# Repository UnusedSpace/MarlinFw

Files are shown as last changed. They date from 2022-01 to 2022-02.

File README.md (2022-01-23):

# Dokumentation

## Inhalt

### [Marlin Firmware - Fork Unused Space](./marlinfw/readme.md)

- Hardware
- Software
- Installation
- Konfiguration

### [PrusaSlicer](./prusaslicer/readme.md)

- Installation
- Konfiguration

### [Raspberry](./raspberry/readme.md)

- OctoPrint | Raspbian
  - Installation
  - Konfiguration

- OctoPi
  - Installation
  - Konfiguration

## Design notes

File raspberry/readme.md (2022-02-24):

# Raspberry

## **Hardware**
Folgende Einplatinenrechner wurden erfolgreich getestet
| Einplatinenrechner | Version |
| :- | :- |
| Raspberry Pi 3 | B+ |
| Raspberry Pi 4 | 4GB |

Raspberry Pi Zero, Raspberry Pi Zero W werden aufgrund der erhöhten Hardwareanforderungen nicht empfohlen!
<br><br>

## **Software**

| Datei | Version (**) | Link |
| :- | -: | :-: |
| Raspberry Pi Imager | 1.6.2 | [Webseite](https://www.raspberrypi.com/software/) |
| Raspberry Pi OS Lite (*) | Bullseye - 30.10.2021 | [Webseite](https://https://www.raspberrypi.com/software/operating-systems/) |
| OctoPi & OctoPrint (*) | 0.18.0 & 1.7.3 | [Webseite](https://github.com/OctoPrint/OctoPi-UpToDate/releases) |

(*) Aufzählung dient zur Versionskontrolle und müssen bei Nutzung des Raspberry Pi Imager nicht zurätzlich herunter geladen werden. <br>
(**) Die Versionen beziehen sich auf den Zeitpunkt der Erstellung dieser Dokumentation.
<br>Als Grundsystem für diese Dokumentation liegt Windows 10 vor.

<br>

## Software - Installation | Konfiguration

<details>
<summary><b><i> Raspberry Pi Imager </i></b></summary>

Empfohlen wird eine Class10 SD-Karte mit mindestens 8GB Flashspeicher. Diese kann nun eingelegt und im Hauptmenü unter *SD-KARTE WÄHLEN" ausgewählt werden.

Vorbereitend für die beschriebenen Varianten werden folgende Konfigurationen über *Erweiterte Optionen* (erreichbar über Strg+Shift+X) getroffen:

- *Hostname* aktivieren und vergeben
- *SSH aktivieren* und Passwort vergeben
- *Wifi einrichten* aktivieren und Anmeldeinformationen eingeben
- *Spracheinstellungen festlegen* aktivieren und konfigurieren

</details>

<details>
    <summary><b><i> Variante: Raspbian & OctoPrint </i></b></summary>

Text

*   <details>
    <summary><b><i> Raspbian </i></b></summary>

    Die folgende Anleitung ist nicht als Komplettdokumentation zu sehen! Sie beschreibt lediglich einen oberflächlichen Weg zu einem funktionsfähigem Steuersystem eines 3D-Druckers.

    *   <details>
        <summary><b><i> Installation | Flash </i></b></summary>

        Über den Menüpunkt *OS WÄHLEN* wird das Image unter *Raspberry Pi OS (other) > raspberry Pi OS Lite (32-bit)* ausgewählt und über den Menüpunkt *SCHREIBEN* auf die SD-Karte übertragen.

        Nach dem Schreibvorgang kann die SD-Karte in einen Raspberry eingelegt und jener gestartet werden.

        Der Erste Bootvorgang und die Einwahl in das LAN/WLAN kann bis zu 2 Minuten in Anspruch nehmen!

        </details>

    *   <details>
        <summary><b><i> Konfiguration </i></b></summary>

        Per Kommandozeile wird nun eine SSH-Verbindung aufgebaut:

        > ssh pi@\<HOSTNAME>

        > ssh pi@\<IP>

        Im Anschluss werden folgende Einstellungen getroffen:

        Ein gesondertes Passwort für *root* setzen

        > sudo passwd

        *Raspberry Pi Software Configuration Tool* aufrufen und diverse Einstellungen treffen

        > sudo raspi-config

        - Beim Booten auf eine Netzwerkverbindung warten
            > 1 System Options > S6 Network at Boot > Yes

        - Raspberry Pi Camera-Option aktivieren
            > 3 Interface Options > P1 Camera > Yes

        - Systemsprache ändern
            > 5 Localisation Options > L1 Locale > de_DE.UTF-8 UTF-8 aktivieren
            
            > Systemsprache auf de_DE.UTF-8 ändern

        Paketlisten aktualisieren

        > sudo apt-get update

        System aktualisieren

        > sudo apt-get upgrade

        Nicht mehr benötigte bzw. nicht mehr unterstützte Pakete deinstallieren

        > sudo apt-get autoremove

        Das System neustarten, um die Änderungen zu initialisieren

        > sudo reboot now

        </details>

    </details>

*   <details>
    <summary><b><i> OctoPrint </i></b></summary>

    Text

    *   <details>
        <summary><b><i> Installation </i></b></summary>

        Text

        Abhängigkeiten nachinstallieren

        > sudo apt install python3-pip python3-dev python3-setuptools python3-venv git haproxy

        OctoPrint Ordner erstellen und aufrufen

        > mkdir OctoPrint && cd OctoPrint

        Eine virtuelle Umwelt für Octoprint aktivieren

        > python3 -m venv venv
        > source venv/bin/activate

        PIP upgraden

        > pip install pip --upgrade
        
        OctoPrint installieren

        > pip install octoprint

        User \<Pi> zur Dialout-Gruppe hinzufügen

        > sudo usermod -a -G tty pi

        > sudo usermod -a -G dialout pi

        Vorbereitungen für den Autostart von OctoPrint

        > wget https://github.com/OctoPrint/OctoPrint/raw/master/scripts/octoprint.service && sudo mv octoprint.service /etc/systemd/system/octoprint.service

        Autostart für OctoPrint aktivieren

        > sudo systemctl enable octoprint.service

        Das System neustarten, um die Änderungen zu initialisieren

        > sudo reboot now

        </details>

    *   <details>
        <summary><b><i> Konfiguration </i></b></summary>

        Text

        *   <details>
            <summary><b><i> Grundkonfiguration </i></b></summary>

            Nach erfolgreicher Installation kann OctoPrint über das WebInterface aufgerufen und Konfiguriert werden.

            > http://\<IP>:5000

            > http://\<HOSTNAME>:5000

            Die folgenden Einstellungen sind selbsterklärend und sollten aufmerksam durchgelesen und mit bedacht ausgefüllt werden. 
            
            Folgende Empfehlungen sollten beachtet werden:

            - Zugangsbeschränkung > Ein Useraccount mit sicherem Passwort anlgegen
            - Onlineprüfung aktivieren
            - Plugin Blackliste aktivieren
            - Druckerprofil anlegen

              *   <details>
                  <summary><b><i> Ender-5 </i></b></summary>

                  Allgemein

                  > Name > Ender-5

                  > Modell > Creality

                  Druckbett & -volumen

                  > Breite (X) > 235

                  > Tiefe (Y) > 235

                  > Höhe (Z) > 300

                  Achsen

                  > Z-Achse invertieren

                  </details>

              *   <details>
                  <summary><b><i> Ender-5 Plus </i></b></summary>

                  Allgemein

                  > Name > Ender-5 Plus

                  > Modell > Creality

                  Druckbett & -volumen

                  > Breite (X) > 330

                  > Tiefe (Y) > 330

                  > Höhe (Z) > 400

                  Achsen

                  > ???Z-Achse invertieren

                  </details>

            - Serverbefehle
              - OctoPrint neustarten
                > sudo service octoprint restart
              - System neustarten
                > sudo shutdown -r now
              - System herunterfahren
                > sudo shutdown -h now

            - Webcam & Zeitraffer
              - Stream-URL
                > /webcam/?action=stream
              - Snapshot-URL
                > http://127.0.0.1:8080/?action=snapshot
              - Pfad zu FFMPEG
                > /usr/bin/ffmpeg

            Der Wizard-Einstellungen sind nun gesetzt. Ab hier werden alle Einstellungen über das OctoPrint eigene Menü (erreichbar über das Maulschlüsselsymbol oben rechts) erledigt.

            - Drucker > Temperaturen > Voreinstellungen

                | | Extruder | Bett |
                | :- | :-: | :-: |
                | Vorwärmen | 65 | 65 |

            - Drucker > GCODE Scripts

              *   <details>
                  <summary><b><i> Ender-5 </i></b></summary>

                  > Vor dem Start eines Druckjobs
                  > ```
                  > G28								; Homing

                  > Nach Vollendung eines Druckjobs
                  > ```
                  > G91								; Aktuelle Position relativieren
                  > G1 E-5							; Hotend 5mm Retract
                  > G1 Z5							; Hotend um 5mm vom Bauteil entfernen
                  > G28 X Y							; X-Y Achse in HomePosition
                  > M104 S0							; Hotendheizung abschalten
                  > M140 S0							; Bettheizung abschalten
                  > M106 S0							; Bauteileluefter abschalten
                  > M84 X Y E						; X Y E Motoren abschalten
                  > ```

                  > Nach dem Abbruch eines Druckjobs
                  > ```
                  > G91								; Aktuelle Position relativieren
                  > G1 E-5							; Hotend 5mm Retract
                  > G1 Z5							; Hotend um 5mm vom Bauteil entfernen
                  > G28 X Y							; X-Y Achse in HomePosition
                  > M104 S0							; Hotendheizung abschalten
                  > M140 S0							; Bettheizung abschalten
                  > M106 S0							; Bauteileluefter abschalten
                  > M84 X Y E						; X Y E Motoren abschalten

                  > After serial connection to printer is established
                  > ```
                  > M42 I1 P5 S255					; Hotendluefuter einschalten
                  > M42 I1 P6 S255					; Boardluefter einschalten
                  > G28 X Y							; Homing X- Y-Achse

                  > Before serial connection to printer is closed
                  > ```
                  > M104 S0							; Hotendheizung abschalten
                  > M140 S0							; Bettheizung abschalten
                  > M84								; Alle Motoren abschalten

                  </details>

              *   <details>
                  <summary><b><i> Ender-5 Plus </i></b></summary>

                  > Vor dem Start eines Druckjobs
                  > ```
                  > M301 E0 P28.08 I2.79 D70.67		; PID-Tuning Nozzle 2021-11-24
                  > M304 E-1 P119.40 I10.21 D930.67	; PID-Tuning Bed 2021-11-24
                  > M851 Z-2.75						; Z-Probe Offset 2021-12-15
                  > G28								; Homing

                  > Nach Vollendung eines Druckjobs
                  > ```
                  > G91								; Aktuelle Position relativieren
                  > G1 E-5							; Hotend 5mm Retract
                  > G1 Z5							; Hotend um 5mm vom Bauteil entfernen
                  > G28 X Y							; X-Y Achse in HomePosition
                  > M104 S0							; Hotendheizung abschalten
                  > M140 S0							; Bettheizung abschalten
                  > M106 S0							; Bauteileluefter abschalten
                  > M84 X Y E						; X Y E Motoren abschalten
                  > ```

                  > Nach dem Abbruch eines Druckjobs
                  > ```
                  > G91								; Aktuelle Position relativieren
                  > G1 E-5							; Hotend 5mm Retract
                  > G1 Z5							; Hotend um 5mm vom Bauteil entfernen
                  > G28 X Y							; X-Y Achse in HomePosition
                  > M104 S0							; Hotendheizung abschalten
                  > M140 S0							; Bettheizung abschalten
                  > M106 S0							; Bauteileluefter abschalten
                  > M84 X Y E						; X Y E Motoren abschalten

                  > After serial connection to printer is established
                  > ```
                  > M301 E0 P28.08 I2.79 D70.67		; PID-Tuning Nozzle 2021-11-24
                  > M304 E-1 P119.40 I10.21 D930.67	; PID-Tuning Bed 2021-11-24
                  > M851 Z-2.75						; Z-Probe Offset 2021-12-15
                  > G28 X Y							; Homing X- Y-Achse

                  > Before serial connection to printer is closed
                  > ```
                  > M104 S0							; Hotendheizung abschalten
                  > M140 S0							; Bettheizung abschalten
                  > M84								; Alle Motoren abschalten

                  </details>

            </details>

        *   <details>
            <summary><b><i> Optionale Erweiterungen </i></b></summary>

            Text

            </details>

        </details>

    </details>

</details>

<details>
    <summary><b><i> Variante: OctoPi & OctoPrint </i></b></summary>

Text

*   <details>
    <summary><b><i> Mehrere Drucker an einem Raspberry </i></b></summary>

    Video
    https://www.youtube.com/watch?v=GEgukBiLnmM

    > 2. Instanz > Ordner erstellen
    > ```
    > cp -R /home/pi/.octoprint /home/pi/.octoprint2
    
    > 3. Instanz > Ordner erstellen
    > ```
    > cp -R /home/pi/.octoprint /home/pi/.octoprint3

    > Als SuperUser anmelden
    > ```
    > sudo su root

    > In den Dienste-Ordner wechseln
    > ```
    > cd /etc/systemd/system/

    > 2. Instanz > Dienst erstellen
    > ```
    > cp ./octoprint.service ./octoprint2.service

    > 3. Instanz > Dienst erstellen
    > ```
    > cp ./octoprint.service ./octoprint3.service

    > 2. Instanz > Erforderliche Daten kopieren
    > ```
    > sudo sed s/127.0.0.1/0.0.0.0/ < octoprint.service | sed s/5000/5001/ | sed s/--port=\${PORT}/--port=\${PORT}\ --basedir=\\/home\\/pi\\/\.octoprint2/ > octoprint2.service

    > 3. Instanz > Erforderliche Daten kopieren
    > ```
    > sudo sed s/127.0.0.1/0.0.0.0/ < octoprint.service | sed s/5000/5002/ | sed s/--port=\${PORT}/--port=\${PORT}\ --basedir=\\/home\\/pi\\/\.octoprint3/ > octoprint3.service

    > 2. Instanz > Im Autostart aufnehmen
    > ```
    > systemctl enable octoprint2

    > 3. Instanz > Im Autostart aufnehmen
    > ```
    > systemctl enable octoprint3

    > 2. Instanz > Instanz starten
    > ```
    > systemctl start octoprint2

    > 3. Instanz > Instanz starten
    > ```
    > systemctl start octoprint3

    WICHTIG:
    Systemkommando [Neustart OctoPrint] anpassen
    OctoPrint > Einstellungen > OctoPrint > Server > Commandos >> octoprint zu octoprint2 etc.

    > Ersten Drucker mit einem freien USB-Port verbinden und über folgenden Befehl ausfindig machen
    > ```
    > tail -F /var/log/messages

    > Falls der Befehl zu langsam, folgenden Befehl ausführen und "ausgabe.txt" per Nano durchsuchen
    > ```
    > sudo cat /var/log/messages > ausgabe.txt

    usb 1-1.1 oder usb 1-1.2 oder usb 1-1.3 oder usb 1-1.4
    Wichtige Daten aus dem String:
    idVendor=****
    idProduct=****
    SerialNumber=*********************
    devpath=*.*
    SYMLINK=[Druckername]

    > 99-usb.rules öffnen
    > ```
    > sudo nano /etc/udev/rules.d/99-usb.rules Default
    
    > 99-usb.rules Datei mit den USB-Linkungen füllen
    > ```
    > SUBSYSTEM=="tty", ATTRS{idVendor}=="1d50", ATTRS{idProduct}=="6029", ATTRS{serial}=="18004010AF6998C15E42D714F50020C0", SYMLINK+="Alpha"
    > SUBSYSTEM=="tty", ATTRS{idVendor}=="1d50", ATTRS{idProduct}=="6029", ATTRS{serial}=="0700B005AF6998C15E4279EFF50020C5", SYMLINK+="Bravo"
    > SUBSYSTEM=="tty", ATTRS{idVendor}=="1d50", ATTRS{idProduct}=="6029", ATTRS{serial}=="1100900AAF6998C05E40D671F50020C0", SYMLINK+="Charlie"
    
    > OctoPrint > Einstellungen > Drucker > Serielle Verbindungen > Weitere Serielle Ports eintragen
    > ```
    > /dev/[Druckername]

    > Raspberry neustarten
    > ```
    > sudo reboot now

    > OctoPrint > Verbindungen > Serieller Port auswählen
    > ```
    > /dev/[Druckername]

    </details>

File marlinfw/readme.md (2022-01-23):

# Marlin Firmware

## **Hardware**
Jeder 3D-Drucker und deren Modifikationen sind differenziert zu konfigurieren.

In diesem Repository werden folgende Drucker- und Motherboard-Kombinationen behandelt
| 3D-Drucker (*) | Board (*) | Steppertreiber (*) |
| :- | :- | :- |
| [Creality Ender-5](./datasheets/creality_ender-5/) | [MKS Gen 1.4](./datasheets/mks_gen_1.4/) | [TMC2208](./datasheets/tmc2208/) |
| [Creality Ender-5 Plus](./datasheets/creality_ender-5_plus/) | [SKR 1.4 Turbo](./datasheets/skr_1.4_turbo/) | [TMC2209](./datasheets/tmc2209/) |

(*) Die Datenblätter sind hinter den Links erreichbar.
<br><br>

## **Software**

| Datei | Version (**) | Link |
| :- | -: | :-: |
| Visual Studio Code | 1.63.2 | [Webseite](https://code.visualstudio.com/download) |
| + PlatformIO IDE | 2.100.151 | VSCode-Tastenkombination <STRG+UMSCHALT+X> |
| + C/C++ | 1.7.1 | VSCode-Tastenkombination <STRG+UMSCHALT+X> |
| + C/C++ Extension Pack | 1.1.0 | VSCode-Tastenkombination <STRG+UMSCHALT+X> |
| Git | 2.34.1 | [Webseite](https://git-scm.com/download/) |
| GitHub Desktop | 2.9.6 | [Webseite](https://desktop.github.com/) |
| Marlin Firmware | 2.0.9.2 | [Webseite](https://marlinfw.org/meta/download/) \| [GitHub](https://github.com/MarlinFirmware/Marlin) |
| - `Fork` UnusedSpace | 2.0.9.2 | [GitHub UnusedSpace](https://github.com/UnusedSpace/MarlinFw) |

(**) Die Versionen beziehen sich auf den Zeitpunkt der Erstellung dieser Dokumentation.
<br>Als Grundsystem für diese Dokumentation liegt Windows 10 vor.

<br>

## Software - Installation | Konfiguration
<details>
    <summary><b><i> Visual Studio Code </i></b></summary>

Die Grundinstallation erfolgt nach dem Download wie gewohnt. Nach dem ersten Start kann das Sprachpaket heruntergeladen und aktiviert werden.

Erforderliche Erweiterungen
- `PlatformIO IDE` (Erforderlicher Compiler für MarlinFirmware)
- `C/C++` (Genutzte Programmiersprache der MarlinFirmware)
- `C/C++` Extension Pack (Diverse nützliche Erweiterungen der Programmiersprache)

</details>

<details>
    <summary><b><i> Git for Windows </i></b></summary>

Die Installation erfordert einige Voreinstellungen, welche sich nach den Gewohnheiten und genutzten Sub-Programmen des jeweiligen Nutzers orientiert.

Optionale Voreinstellungen
- Default Editor used by Git *->* Use Visual Studio Code as Git's default Editor
- Name of the initial branch in new repositories *->* Let Git decide
- PATH Environment *->* Git from the command line and also from 3rd-party software
- SSH executable *->* Use external OpenSSH
- HTTPS transport backend *->* Use the native Windows Secure Channel library
- Line ending conversions *->* Checkout Windows-style, commit Unix-style line endings
- Terminal emulator to use with Git Bash *->* Use Windows' default console window
- Default behaviour of \`git pull` *->* Default (fast-forward or merge)
- Credential helper *->* Git Credential Manager
- Extra Options *->* Enable file system caching

</details>

<details>
    <summary><b><i> GitHub Desktop </i></b></summary>

Die Grundinstallation erfolgt nach dem Download wie gewohnt. Ein GitHub-Account ist für den weiteren Verlauf erforderlich.

</details>

<br>

## Marlin Firmware - Download | Konfiguration | Flash
<details>
    <summary><b><i> Download - Original oder Fork </i></b></summary>

Mittels `GitHub Desktop`, dem Punkt `Clone a repository from the Internet...` und die Eingabe der GitHub-Webadresse `https://github.com/MarlinFirmware/Marlin` kann das Original-Repository ge`Clone`d werden.

Die GitHub-Webadresse des hier behandelteten `Fork`s lautet `https://github.com/UnusedSpace/MarlinFw`.

Nachdem das entsprechende Repository heruntergeladen wurde, kann es mit `Open in Visual Studio Code` bearbeitet werden.

</details>

<details>
    <summary><b><i> Konfiguration </i></b></summary>

Konfigurationsanleitungen

  *   <details>
        
       <summary><b> BLTouch Offsets </b></summary>

        Text

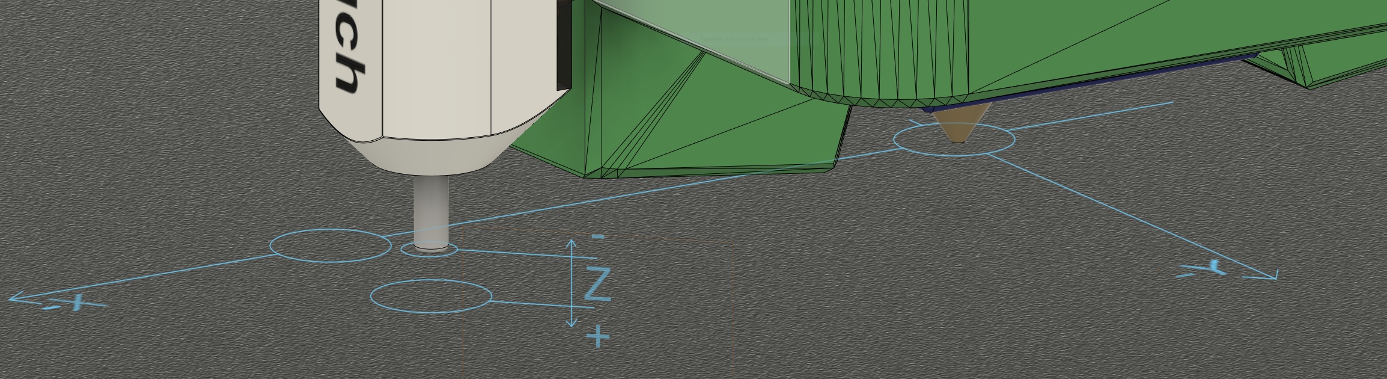
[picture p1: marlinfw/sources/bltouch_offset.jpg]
        

        Text

       </details>

Dateikonfigurationen

   *   <details>
        
       <summary><b> root/platformio.ini </b></summary>

        Um die Firmware für den Chipsatz des Motherboards zu kompilieren, benötigt *PlatformIO* die entsprechenden Informationen. Die Bezeichnung ist dem Datenblatt des jeweiligen Motherboards zu entnehmen.

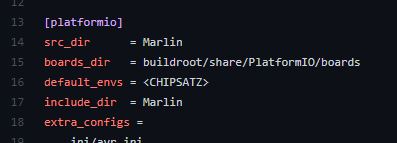
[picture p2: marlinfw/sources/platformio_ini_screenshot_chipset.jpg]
root/platformio.ini - screenshot chipset Dateipfad: root/platformio.ini
        

        | Motherboard | Chipsatz |
        | :- | :- |
        | MKS Gen 1.4 | mega2560 |
        | SKR 1.4 Turbo | LPC1769 |

       </details>

   *   <details>

       <summary><b> root/Marlin/Configuration.h </b></summary>

        In der Datei ***Configuration.h*** wird die generelle Grundkonfiguration vorgenommen. In diesem Setup wird kein Display eingesetzt! Erforderliche und optionale Einstellungen sind als solche gekennzeichnet.

        *   <details>
            
            <summary> <i> Optional </i>- STRING_CONFIG_H_AUTHOR </summary>

            `Description in progress...`

            > Original
            > ```
            > #define STRING_CONFIG_H_AUTHOR "(none, default config)" // Who made the changes.

            > MKS Gen 1.4 | SKR 1.4 Turbo
            > ```
            > #define STRING_CONFIG_H_AUTHOR "(UnusedSpace | MarlinFw <VERSION>)" // Who made the changes.

            </details>

        *   <details>
            
            <summary> <i> Optional </i>- SHOW_BOOTSCREEN </summary>

            `Description in progress...`

            > Original
            > ```
            > #define SHOW_BOOTSCREEN

            > MKS Gen 1.4 | SKR 1.4 Turbo
            > ```
            > //#define SHOW_BOOTSCREEN
            
            </details>

        *   <details>
            
            <summary> <i> Erforderlich </i>- SERIAL_PORT </summary>

            `Description in progress...`

            > Original
            > ```
            > #define SERIAL_PORT 0

            > MKS Gen 1.4
            > ```
            > #define SERIAL_PORT 0

            > SKR 1.4 Turbo
            > ```
            > #define SERIAL_PORT -1
            
            </details>

        *   <details>
            
            <summary> <i> Erforderlich </i>- BAUDRATE </summary>

            `Description in progress...`

            > Original
            > ```
            > #define BAUDRATE 250000

            > MKS Gen 1.4 | SKR 1.4 Turbo
            > ```
            > #define BAUDRATE 115200
            
            </details>

        *   <details>
            
            <summary> <i> Erforderlich </i>- MOTHERBOARD </summary>

            `Description in progress...`

            > Original
            > ```
            > #define MOTHERBOARD BOARD_RAMPS_14_EFB

            > MKS Gen 1.4
            > ```
            > #define MOTHERBOARD BOARD_MKS_GEN_13

            > SKR 1.4 Turbo
            > ```
            > #define MOTHERBOARD BOARD_BTT_SKR_V1_4_TURBO
            
            </details>

        *   <details>
            
            <summary> <i> Optional </i>- CUSTOM_MACHINE_NAME </summary>

            `Description in progress...`

            > Original
            > ```
            > //#define CUSTOM_MACHINE_NAME "3D Printer"

            > MKS Gen 1.4
            > ```
            > #define CUSTOM_MACHINE_NAME "Creality Ender-5"

            > SKR 1.4 Turbo
            > ```
            > #define CUSTOM_MACHINE_NAME "Creality Ender-5 Plus"
            
            </details>

        *   <details>
            
            <summary> <i> Erforderlich </i>- TEMP_SENSOR_BED </summary>

            `Description in progress...`

            > Original
            > ```
            > #define TEMP_SENSOR_BED 0

            > MKS Gen 1.4 | SKR 1.4 Turbo
            > ```
            > #define TEMP_SENSOR_BED 1
            
            </details>

        *   <details>
            <summary> <i> Optional </i>- PID_PARAMS_PER_HOTEND </summary>

            `Description in progress...`

            > Original
            > ```
            > #if ENABLED(PIDTEMP)
            >   //#define PID_EDIT_MENU         // Add PID editing to the "Advanced Settings" menu. (~700 bytes of PROGMEM)
            >   //#define PID_AUTOTUNE_MENU     // Add PID auto-tuning to the "Advanced Settings" menu. (~250 bytes of PROGMEM)
            >   //#define PID_PARAMS_PER_HOTEND // Uses separate PID parameters for each extruder (useful for mismatched extruders)
            >                                   // Set/get with gcode: M301 E[extruder number, 0-2]
            >
            >   #if ENABLED(PID_PARAMS_PER_HOTEND)
            >     // Specify up to one value per hotend here, according to your setup.
            >     // If there are fewer values, the last one applies to the remaining hotends.
            >     #define DEFAULT_Kp_LIST {  22.20,  22.20 }
            >     #define DEFAULT_Ki_LIST {   1.08,   1.08 }
            >     #define DEFAULT_Kd_LIST { 114.00, 114.00 }
            >   #else
            >     #define DEFAULT_Kp  22.20
            >     #define DEFAULT_Ki   1.08
            >     #define DEFAULT_Kd 114.00
            >   #endif
            > #endif // PIDTEMP

            > MKS Gen 1.4
            > ```
            > #if ENABLED(PIDTEMP)
            >   //#define PID_EDIT_MENU         // Add PID editing to the "Advanced Settings" menu. (~700 bytes of PROGMEM)
            >   //#define PID_AUTOTUNE_MENU     // Add PID auto-tuning to the "Advanced Settings" menu. (~250 bytes of PROGMEM)
            >   //#define PID_PARAMS_PER_HOTEND // Uses separate PID parameters for each extruder (useful for mismatched extruders)
            >                                   // Set/get with gcode: M301 E[extruder number, 0-2]
            >
            >   #if ENABLED(PID_PARAMS_PER_HOTEND)
            >     // Specify up to one value per hotend here, according to your setup.
            >     // If there are fewer values, the last one applies to the remaining hotends.
            >     #define DEFAULT_Kp_LIST {  22.20,  22.20 }
            >     #define DEFAULT_Ki_LIST {   1.08,   1.08 }
            >     #define DEFAULT_Kd_LIST { 114.00, 114.00 }
            >   #else
            >     #define DEFAULT_Kp  30.50
            >     #define DEFAULT_Ki   3.92
            >     #define DEFAULT_Kd  59.34
            >   #endif
            > #endif // PIDTEMP

            > SKR 1.4 Turbo - Drucker 1
            > ```
            > #if ENABLED(PIDTEMP)
            >   //#define PID_EDIT_MENU         // Add PID editing to the "Advanced Settings" menu. (~700 bytes of PROGMEM)
            >   //#define PID_AUTOTUNE_MENU     // Add PID auto-tuning to the "Advanced Settings" menu. (~250 bytes of PROGMEM)
            >   //#define PID_PARAMS_PER_HOTEND // Uses separate PID parameters for each extruder (useful for mismatched extruders)
            >                                   // Set/get with gcode: M301 E[extruder number, 0-2]
            >
            >   #if ENABLED(PID_PARAMS_PER_HOTEND)
            >     // Specify up to one value per hotend here, according to your setup.
            >     // If there are fewer values, the last one applies to the remaining hotends.
            >     #define DEFAULT_Kp_LIST {  22.20,  22.20 }
            >     #define DEFAULT_Ki_LIST {   1.08,   1.08 }
            >     #define DEFAULT_Kd_LIST { 114.00, 114.00 }
            >   #else
            >     #define DEFAULT_Kp  28.08
            >     #define DEFAULT_Ki   2.79
            >     #define DEFAULT_Kd  70.67
            >   #endif
            > #endif // PIDTEMP
            
            > SKR 1.4 Turbo - Drucker 2
            > ```
            > #if ENABLED(PIDTEMP)
            >   //#define PID_EDIT_MENU         // Add PID editing to the "Advanced Settings" menu. (~700 bytes of PROGMEM)
            >   //#define PID_AUTOTUNE_MENU     // Add PID auto-tuning to the "Advanced Settings" menu. (~250 bytes of PROGMEM)
            >   //#define PID_PARAMS_PER_HOTEND // Uses separate PID parameters for each extruder (useful for mismatched extruders)
            >                                   // Set/get with gcode: M301 E[extruder number, 0-2]
            >
            >   #if ENABLED(PID_PARAMS_PER_HOTEND)
            >     // Specify up to one value per hotend here, according to your setup.
            >     // If there are fewer values, the last one applies to the remaining hotends.
            >     #define DEFAULT_Kp_LIST {  22.20,  22.20 }
            >     #define DEFAULT_Ki_LIST {   1.08,   1.08 }
            >     #define DEFAULT_Kd_LIST { 114.00, 114.00 }
            >   #else
            >     #define DEFAULT_Kp  30.56
            >     #define DEFAULT_Ki   3.08
            >     #define DEFAULT_Kd  75.82
            >   #endif
            > #endif // PIDTEMP

            > SKR 1.4 Turbo - Drucker 3
            > ```
            > #if ENABLED(PIDTEMP)
            >   //#define PID_EDIT_MENU         // Add PID editing to the "Advanced Settings" menu. (~700 bytes of PROGMEM)
            >   //#define PID_AUTOTUNE_MENU     // Add PID auto-tuning to the "Advanced Settings" menu. (~250 bytes of PROGMEM)
            >   //#define PID_PARAMS_PER_HOTEND // Uses separate PID parameters for each extruder (useful for mismatched extruders)
            >                                   // Set/get with gcode: M301 E[extruder number, 0-2]
            >
            >   #if ENABLED(PID_PARAMS_PER_HOTEND)
            >     // Specify up to one value per hotend here, according to your setup.
            >     // If there are fewer values, the last one applies to the remaining hotends.
            >     #define DEFAULT_Kp_LIST {  22.20,  22.20 }
            >     #define DEFAULT_Ki_LIST {   1.08,   1.08 }
            >     #define DEFAULT_Kd_LIST { 114.00, 114.00 }
            >   #else
            >     #define DEFAULT_Kp  27.11
            >     #define DEFAULT_Ki   2.62
            >     #define DEFAULT_Kd  70.12
            >   #endif
            > #endif // PIDTEMP

            </details>

        *   <details>
            
            <summary> <i> Erforderlich </i>- PIDTEMPBED </summary>

            `Description in progress...`

            > Original
            > ```
            > //#define PIDTEMPBED

            > MKS Gen 1.4 | SKR 1.4 Turbo
            > ```
            > #define PIDTEMPBED
            
            </details>

        *   <details>
            <summary> <i> Optional </i>- PIDTEMPBED </summary>

            `Description in progress...`

            > Original
            > ```
            > #if ENABLED(PIDTEMPBED)
            >   //#define MIN_BED_POWER 0
            >   //#define PID_BED_DEBUG // Sends debug data to the serial port.
            >
            >   // 120V 250W silicone heater into 4mm borosilicate (MendelMax 1.5+)
            >   // from FOPDT model - kp=.39 Tp=405 Tdead=66, Tc set to 79.2, aggressive factor of .15 (vs .1, 1, 10)
            >   #define DEFAULT_bedKp  65.17
            >   #define DEFAULT_bedKi  12.05
            >   #define DEFAULT_bedKd 234.92
            >
            >   // FIND YOUR OWN: "M303 E-1 C8 S90" to run autotune on the bed at 90 degreesC for 8 cycles.
            > #endif // PIDTEMPBED

            > MKS Gen 1.4
            > ```
            > #if ENABLED(PIDTEMPBED)
            >   //#define MIN_BED_POWER 0
            >   //#define PID_BED_DEBUG // Sends debug data to the serial port.
            >
            >   // 120V 250W silicone heater into 4mm borosilicate (MendelMax 1.5+)
            >   // from FOPDT model - kp=.39 Tp=405 Tdead=66, Tc set to 79.2, aggressive factor of .15 (vs .1, 1, 10)
            >   #define DEFAULT_bedKp  53.72
            >   #define DEFAULT_bedKi  10.09
            >   #define DEFAULT_bedKd 190.72
            >
            >   // FIND YOUR OWN: "M303 E-1 C8 S90" to run autotune on the bed at 90 degreesC for 8 cycles.
            > #endif // PIDTEMPBED

            > SKR 1.4 Turbo - Drucker 1
            > ```
            > #if ENABLED(PIDTEMPBED)
            >   //#define MIN_BED_POWER 0
            >   //#define PID_BED_DEBUG // Sends debug data to the serial port.
            >
            >   // 120V 250W silicone heater into 4mm borosilicate (MendelMax 1.5+)
            >   // from FOPDT model - kp=.39 Tp=405 Tdead=66, Tc set to 79.2, aggressive factor of .15 (vs .1, 1, 10)
            >   #define DEFAULT_bedKp 119.40
            >   #define DEFAULT_bedKi  10.21
            >   #define DEFAULT_bedKd 930.67
            >
            >   // FIND YOUR OWN: "M303 E-1 C8 S90" to run autotune on the bed at 90 degreesC for 8 cycles.
            > #endif // PIDTEMPBED
            
            > SKR 1.4 Turbo - Drucker 2
            > ```
            > #if ENABLED(PIDTEMPBED)
            >   //#define MIN_BED_POWER 0
            >   //#define PID_BED_DEBUG // Sends debug data to the serial port.
            >
            >   // 120V 250W silicone heater into 4mm borosilicate (MendelMax 1.5+)
            >   // from FOPDT model - kp=.39 Tp=405 Tdead=66, Tc set to 79.2, aggressive factor of .15 (vs .1, 1, 10)
            >   #define DEFAULT_bedKp 109.47
            >   #define DEFAULT_bedKi   9.23
            >   #define DEFAULT_bedKd 866.09
            >
            >   // FIND YOUR OWN: "M303 E-1 C8 S90" to run autotune on the bed at 90 degreesC for 8 cycles.
            > #endif // PIDTEMPBED

            > SKR 1.4 Turbo - Drucker 3
            > ```
            > #if ENABLED(PIDTEMPBED)
            >   //#define MIN_BED_POWER 0
            >   //#define PID_BED_DEBUG // Sends debug data to the serial port.
            >
            >   // 120V 250W silicone heater into 4mm borosilicate (MendelMax 1.5+)
            >   // from FOPDT model - kp=.39 Tp=405 Tdead=66, Tc set to 79.2, aggressive factor of .15 (vs .1, 1, 10)
            >   #define DEFAULT_bedKp 132.86
            >   #define DEFAULT_bedKi  12.09
            >   #define DEFAULT_bedKd 973.49
            >
            >   // FIND YOUR OWN: "M303 E-1 C8 S90" to run autotune on the bed at 90 degreesC for 8 cycles.
            > #endif // PIDTEMPBED

            </details>

        *   <details>
            
            <summary> <i> Erforderlich </i>- Endstop Settings </summary>

            `Description in progress...`

            > Original
            > ```
            > // Specify here all the endstop connectors that are connected to any endstop or probe.
            > // Almost all printers will be using one per axis. Probes will use one or more of the
            > // extra connectors. Leave undefined any used for non-endstop and non-probe purposes.
            > #define USE_XMIN_PLUG
            > #define USE_YMIN_PLUG
            > #define USE_ZMIN_PLUG
            > //#define USE_IMIN_PLUG
            > //#define USE_JMIN_PLUG
            > //#define USE_KMIN_PLUG
            > //#define USE_XMAX_PLUG
            > //#define USE_YMAX_PLUG
            > //#define USE_ZMAX_PLUG
            > //#define USE_IMAX_PLUG
            > //#define USE_JMAX_PLUG
            > //#define USE_KMAX_PLUG

            > MKS Gen 1.4 | SKR 1.4 Turbo
            > ```
            > // Specify here all the endstop connectors that are connected to any endstop or probe.
            > // Almost all printers will be using one per axis. Probes will use one or more of the
            > // extra connectors. Leave undefined any used for non-endstop and non-probe purposes.
            > //#define USE_XMIN_PLUG
            > //#define USE_YMIN_PLUG
            > #define USE_ZMIN_PLUG
            > //#define USE_IMIN_PLUG
            > //#define USE_JMIN_PLUG
            > //#define USE_KMIN_PLUG
            > #define USE_XMAX_PLUG
            > #define USE_YMAX_PLUG
            > //#define USE_ZMAX_PLUG
            > //#define USE_IMAX_PLUG
            > //#define USE_JMAX_PLUG
            > //#define USE_KMAX_PLUG
            
            </details>

        *   <details>
            
            <summary> <i> Erforderlich </i>- Stepper Drivers </summary>

            `Description in progress...`

            > Original
            > ```
            > #define X_DRIVER_TYPE  A4988
            > #define Y_DRIVER_TYPE  A4988
            > #define Z_DRIVER_TYPE  A4988
            > //#define X2_DRIVER_TYPE A4988
            > //#define Y2_DRIVER_TYPE A4988
            > //#define Z2_DRIVER_TYPE A4988
            > //#define Z3_DRIVER_TYPE A4988
            > //#define Z4_DRIVER_TYPE A4988
            > //#define I_DRIVER_TYPE  A4988
            > //#define J_DRIVER_TYPE  A4988
            > //#define K_DRIVER_TYPE  A4988
            > #define E0_DRIVER_TYPE A4988
            > //#define E1_DRIVER_TYPE A4988
            > //#define E2_DRIVER_TYPE A4988
            > //#define E3_DRIVER_TYPE A4988
            > //#define E4_DRIVER_TYPE A4988
            > //#define E5_DRIVER_TYPE A4988
            > //#define E6_DRIVER_TYPE A4988
            > //#define E7_DRIVER_TYPE A4988

            > MKS Gen 1.4
            > ```
            > #define X_DRIVER_TYPE  TMC2208
            > #define Y_DRIVER_TYPE  TMC2208
            > #define Z_DRIVER_TYPE  TMC2208
            > //#define X2_DRIVER_TYPE A4988
            > //#define Y2_DRIVER_TYPE A4988
            > //#define Z2_DRIVER_TYPE A4988
            > //#define Z3_DRIVER_TYPE A4988
            > //#define Z4_DRIVER_TYPE A4988
            > //#define I_DRIVER_TYPE  A4988
            > //#define J_DRIVER_TYPE  A4988
            > //#define K_DRIVER_TYPE  A4988
            > #define E0_DRIVER_TYPE TMC2208
            > //#define E1_DRIVER_TYPE A4988
            > //#define E2_DRIVER_TYPE A4988
            > //#define E3_DRIVER_TYPE A4988
            > //#define E4_DRIVER_TYPE A4988
            > //#define E5_DRIVER_TYPE A4988
            > //#define E6_DRIVER_TYPE A4988
            > //#define E7_DRIVER_TYPE A4988

            > SKR 1.4 Turbo
            > ```
            > #define X_DRIVER_TYPE  TMC2209
            > #define Y_DRIVER_TYPE  TMC2209
            > #define Z_DRIVER_TYPE  TMC2209
            > //#define X2_DRIVER_TYPE A4988
            > //#define Y2_DRIVER_TYPE A4988
            > //#define Z2_DRIVER_TYPE A4988
            > //#define Z3_DRIVER_TYPE A4988
            > //#define Z4_DRIVER_TYPE A4988
            > //#define I_DRIVER_TYPE  A4988
            > //#define J_DRIVER_TYPE  A4988
            > //#define K_DRIVER_TYPE  A4988
            > #define E0_DRIVER_TYPE TMC2209
            > //#define E1_DRIVER_TYPE A4988
            > //#define E2_DRIVER_TYPE A4988
            > //#define E3_DRIVER_TYPE A4988
            > //#define E4_DRIVER_TYPE A4988
            > //#define E5_DRIVER_TYPE A4988
            > //#define E6_DRIVER_TYPE A4988
            > //#define E7_DRIVER_TYPE A4988
            
            </details>

        *   <details>
            
            <summary> <i> Erforderlich </i>- DEFAULT_AXIS_STEPS_PER_UNIT </summary>

            `Description in progress...`

            > Original
            > ```
            > #define DEFAULT_AXIS_STEPS_PER_UNIT   { 80, 80, 400, 500 }

            > MKS Gen 1.4
            > ```
            > #define DEFAULT_AXIS_STEPS_PER_UNIT   { 80, 80, 400, 137.97 }

            > SKR 1.4 Turbo
            > ```
            > #define DEFAULT_AXIS_STEPS_PER_UNIT   { 40, 40, 400, 68.29 }
            
            </details>

        *   <details>
            
            <summary> <i> Erforderlich </i>- DEFAULT_MAX_ACCELERATION </summary>

            `Description in progress...`

            > Original
            > ```
            > #define DEFAULT_MAX_ACCELERATION      { 3000, 3000, 100, 10000 }

            > MKS Gen 1.4 | SKR 1.4 Turbo
            > ```
            > #define DEFAULT_MAX_ACCELERATION      { 500, 500, 100, 5000 }
            
            </details>

        *   <details>
            
            <summary> <i> Erforderlich </i>- DEFAULT_ACCELERATION </summary>

            `Description in progress...`

            > Original
            > ```
            > #define DEFAULT_ACCELERATION          3000    // X, Y, Z and E acceleration for printing moves
            > #define DEFAULT_RETRACT_ACCELERATION  3000    // E acceleration for retracts
            > #define DEFAULT_TRAVEL_ACCELERATION   3000    // X, Y, Z acceleration for travel (non printing) moves

            > MKS Gen 1.4 | SKR 1.4 Turbo
            > ```
            > #define DEFAULT_ACCELERATION          500  // X, Y, Z and E acceleration for printing moves
            > #define DEFAULT_RETRACT_ACCELERATION  500  // E acceleration for retracts
            > #define DEFAULT_TRAVEL_ACCELERATION   500  // X, Y, Z acceleration for travel (non printing) moves
            
            </details>

        *   <details>
            
            <summary> <i> Erforderlich </i>- Z_MIN_PROBE_USES_Z_MIN_ENDSTOP_PIN </summary>

            `Description in progress...`

            > Original
            > ```
            > #define Z_MIN_PROBE_USES_Z_MIN_ENDSTOP_PIN

            > SKR 1.4 Turbo
            > ```
            > //#define Z_MIN_PROBE_USES_Z_MIN_ENDSTOP_PIN
            
            </details>

        *   <details>
            
            <summary> <i> Erforderlich </i>- Z_MIN_PROBE_PIN </summary>

            `Description in progress...`

            > Original
            > ```
            > //#define Z_MIN_PROBE_PIN 32 // Pin 32 is the RAMPS default

            > SKR 1.4 Turbo
            > ```
            > #define Z_MIN_PROBE_PIN P0_10 // Pin 32 is the RAMPS default
            
            </details>

        *   <details>
            
            <summary> <i> Erforderlich </i>- BLTOUCH </summary>

            `Description in progress...`

            > Original
            > ```
            > //#define BLTOUCH

            > MKS Gen 1.4 | SKR 1.4 Turbo
            > ```
            > #define BLTOUCH
            
            </details>

        *   <details>
            
            <summary> <i> Erforderlich </i>- NOZZLE_TO_PROBE_OFFSET </summary>

            `Description in progress...`

            > Original
            > ```
            > #define NOZZLE_TO_PROBE_OFFSET { 10, 10, 0 }

            > MKS Gen 1.4
            > ```
            > #define NOZZLE_TO_PROBE_OFFSET { -50.0, -10.0, 0 }

            > SKR 1.4 Turbo
            > ```
            > #define NOZZLE_TO_PROBE_OFFSET { -44.0, -5.0, 0 }
            
            </details>

        *   <details>
            
            <summary> <i> Erforderlich </i>- Stepper direction </summary>

            `Description in progress...`

            > Original
            > ```
            > // Invert the stepper direction. Change (or reverse the motor connector) if an axis goes the wrong way.
            > #define INVERT_X_DIR false
            > #define INVERT_Y_DIR true
            > #define INVERT_Z_DIR false
            > //#define INVERT_I_DIR false
            > //#define INVERT_J_DIR false
            > //#define INVERT_K_DIR false
            >
            > // @section extruder
            >
            > // For direct drive extruder v9 set to true, for geared extruder set to false.
            > #define INVERT_E0_DIR false
            > #define INVERT_E1_DIR false
            > #define INVERT_E2_DIR false
            > #define INVERT_E3_DIR false
            > #define INVERT_E4_DIR false
            > #define INVERT_E5_DIR false
            > #define INVERT_E6_DIR false
            > #define INVERT_E7_DIR false

            > MKS Gen 1.4
            > ```
            > // Invert the stepper direction. Change (or reverse the motor connector) if an axis goes the wrong way.
            > #define INVERT_X_DIR false
            > #define INVERT_Y_DIR false
            > #define INVERT_Z_DIR false
            > //#define INVERT_I_DIR false
            > //#define INVERT_J_DIR false
            > //#define INVERT_K_DIR false
            >
            > // @section extruder
            >
            > // For direct drive extruder v9 set to true, for geared extruder set to false.
            > #define INVERT_E0_DIR true
            > #define INVERT_E1_DIR false
            > #define INVERT_E2_DIR false
            > #define INVERT_E3_DIR false
            > #define INVERT_E4_DIR false
            > #define INVERT_E5_DIR false
            > #define INVERT_E6_DIR false
            > #define INVERT_E7_DIR false

            > SKR 1.4 Turbo
            > ```
            > // Invert the stepper direction. Change (or reverse the motor connector) if an axis goes the wrong way.
            > #define INVERT_X_DIR true
            > #define INVERT_Y_DIR true
            > #define INVERT_Z_DIR true
            > //#define INVERT_I_DIR false
            > //#define INVERT_J_DIR false
            > //#define INVERT_K_DIR false
            >
            > // @section extruder
            >
            > // For direct drive extruder v9 set to true, for geared extruder set to false.
            > #define INVERT_E0_DIR true
            > #define INVERT_E1_DIR false
            > #define INVERT_E2_DIR false
            > #define INVERT_E3_DIR false
            > #define INVERT_E4_DIR false
            > #define INVERT_E5_DIR false
            > #define INVERT_E6_DIR false
            > #define INVERT_E7_DIR false
            
            </details>

        *   <details>
            
            <summary> <i> Erforderlich </i>- Homing </summary>

            `Description in progress...`

            > Original
            > ```
            > //#define NO_MOTION_BEFORE_HOMING // Inhibit movement until all axes have been homed. Also enable HOME_AFTER_DEACTIVATE for extra safety.
            > //#define HOME_AFTER_DEACTIVATE   // Require rehoming after steppers are deactivated. Also enable NO_MOTION_BEFORE_HOMING for extra safety.

            > MKS Gen 1.4 | SKR 1.4 Turbo
            > ```
            > #define NO_MOTION_BEFORE_HOMING // Inhibit movement until all axes have been homed. Also enable HOME_AFTER_DEACTIVATE for extra safety.
            > #define HOME_AFTER_DEACTIVATE   // Require rehoming after steppers are deactivated. Also enable NO_MOTION_BEFORE_HOMING for extra safety.
            
            </details>

        *   <details>
            
            <summary> <i> Erforderlich </i>- Z_HOMING_HEIGHT </summary>

            `Description in progress...`

            > Original
            > ```
            > //#define Z_HOMING_HEIGHT  4        // (mm) Minimal Z height before homing (G28) for Z clearance above the bed, clamps, ...

            > MKS Gen 1.4 | SKR 1.4 Turbo
            > ```
            > #define Z_HOMING_HEIGHT  4        // (mm) Minimal Z height before homing (G28) for Z clearance above the bed, clamps, ...
            
            </details>

        *   <details>
            
            <summary> <i> Erforderlich </i>- Endstops direction </summary>

            `Description in progress...`

            > Original
            > ```
            > // Direction of endstops when homing; 1=MAX, -1=MIN
            > // :[-1,1]
            > #define X_HOME_DIR -1
            > #define Y_HOME_DIR -1
            > #define Z_HOME_DIR -1
            > //#define I_HOME_DIR -1
            > //#define J_HOME_DIR -1
            > //#define K_HOME_DIR -1

            > MKS Gen 1.4 | SKR 1.4 Turbo
            > ```
            > // Direction of endstops when homing; 1=MAX, -1=MIN
            > // :[-1,1]
            > #define X_HOME_DIR  1
            > #define Y_HOME_DIR  1
            > #define Z_HOME_DIR -1
            > //#define I_HOME_DIR -1
            > //#define J_HOME_DIR -1
            > //#define K_HOME_DIR -1
            
            </details>

        *   <details>
            
            <summary> <i> Erforderlich </i>- BED_SIZE </summary>

            `Description in progress...`

            > Original
            > ```
            > // The size of the printable area
            > #define X_BED_SIZE 200
            > #define Y_BED_SIZE 200

            > MKS Gen 1.4
            > ```
            > // The size of the printable area
            > #define X_BED_SIZE 235
            > #define Y_BED_SIZE 230
            
            > SKR 1.4 Turbo
            > ```
            > // The size of the printable area
            > #define X_BED_SIZE 365
            > #define Y_BED_SIZE 369

            </details>

        *   <details>
            
            <summary> <i> Erforderlich </i>- Z_MAX_POS </summary>

            `Description in progress...`

            > Original
            > ```
            > #define Z_MAX_POS 200

            > MKS Gen 1.4
            > ```
            > #define Z_MAX_POS 300
            
            > SKR 1.4 Turbo
            > ```
            > #define Z_MAX_POS 400

            </details>

        *   <details>
            
            <summary> <i> Erforderlich </i>- MIN_SOFTWARE_ENDSTOPS </summary>

            `Description in progress...`

            > Original
            > ```
            > // Min software endstops constrain movement within minimum coordinate bounds
            > #define MIN_SOFTWARE_ENDSTOPS
            > #if ENABLED(MIN_SOFTWARE_ENDSTOPS)
            >   #define MIN_SOFTWARE_ENDSTOP_X
            >   #define MIN_SOFTWARE_ENDSTOP_Y
            >   #define MIN_SOFTWARE_ENDSTOP_Z
            >   #define MIN_SOFTWARE_ENDSTOP_I
            >   #define MIN_SOFTWARE_ENDSTOP_J
            >   #define MIN_SOFTWARE_ENDSTOP_K
            > #endif

            > MKS Gen 1.4 | SKR 1.4 Turbo
            > ```
            > // Min software endstops constrain movement within minimum coordinate bounds
            > #define MIN_SOFTWARE_ENDSTOPS
            > #if ENABLED(MIN_SOFTWARE_ENDSTOPS)
            >   #define MIN_SOFTWARE_ENDSTOP_X
            >   #define MIN_SOFTWARE_ENDSTOP_Y
            >   //#define MIN_SOFTWARE_ENDSTOP_Z
            >   #define MIN_SOFTWARE_ENDSTOP_I
            >   #define MIN_SOFTWARE_ENDSTOP_J
            >   #define MIN_SOFTWARE_ENDSTOP_K
            > #endif
            
            </details>

        *   <details>
            
            <summary> <i> Erforderlich </i>- AUTO_BED_LEVELING_BILINEAR </summary>

            `Description in progress...`

            > Original
            > ```
            > //#define AUTO_BED_LEVELING_BILINEAR

            > MKS Gen 1.4 | SKR 1.4 Turbo
            > ```
            > #define AUTO_BED_LEVELING_BILINEAR
            
            </details>

        *   <details>
            
            <summary> <i> Erforderlich </i>- PREHEAT_BEFORE_LEVELING </summary>

            `Description in progress...`

            > Original
            > ```
            > /**
            > * Auto-leveling needs preheating
            > */
            > #define PREHEAT_BEFORE_LEVELING
            > #if ENABLED(PREHEAT_BEFORE_LEVELING)
            >   #define LEVELING_NOZZLE_TEMP 120   // (°C) Only applies to E0 at this time
            >   #define LEVELING_BED_TEMP     50
            > #endif

            > MKS Gen 1.4 | SKR 1.4 Turbo
            > ```
            > /**
            > * Auto-leveling needs preheating
            > */
            > //#define PREHEAT_BEFORE_LEVELING
            > #if ENABLED(PREHEAT_BEFORE_LEVELING)
            >   #define LEVELING_NOZZLE_TEMP  65   // (°C) Only applies to E0 at this time
            >   #define LEVELING_BED_TEMP     65
            > #endif
            
            </details>

        *   <details>
            
            <summary> <i> Optional </i>- GRID_MAX_POINTS_X </summary>

            `Description in progress...`

            > Original
            > ```
            >   #define GRID_MAX_POINTS_X 3

            > MKS Gen 1.4 | SKR 1.4 Turbo
            > ```
            >   #define GRID_MAX_POINTS_X 5
            
            </details>

        *   <details>
            
            <summary> <i> Erforderlich </i>- Z_SAFE_HOMING </summary>

            `Description in progress...`

            > Original
            > ```
            > //#define Z_SAFE_HOMING

            > MKS Gen 1.4 | SKR 1.4 Turbo
            > ```
            > #define Z_SAFE_HOMING
            
            </details>

        *   <details>
            
            <summary> <i> Erforderlich </i>- NUM_SERVOS </summary>

            `Description in progress...`

            > Original
            > ```
            > //#define NUM_SERVOS 3 // Note: Servo index starts with 0 for M280-M282 commands

            > MKS Gen 1.4
            > ```
            > #define NUM_SERVOS 1 // Note: Servo index starts with 0 for M280-M282 commands
            
            </details>

       </details>

   *   <details>    

       <summary><b> root/Marlin/Configuration_adv.h </b></summary>

        In der Datei ***Configuration_adv.h*** wird die erweiterte Konfiguration vorgenommen. Erforderliche und optionale Einstellungen sind als solche gekennzeichnet.

        *   <details>
            
            <summary> <i> Erforderlich </i>- X_DUAL_STEPPER_DRIVERS </summary>

            `Description in progress...`

            > Original
            > ```
            > //#define X_DUAL_STEPPER_DRIVERS
            > #if ENABLED(X_DUAL_STEPPER_DRIVERS)
            >   //#define INVERT_X2_VS_X_DIR    // Enable if X2 direction signal is opposite to X
            >   //#define X_DUAL_ENDSTOPS
            >   #if ENABLED(X_DUAL_ENDSTOPS)
            >     #define X2_USE_ENDSTOP _XMAX_
            >     #define X2_ENDSTOP_ADJUSTMENT  0
            >   #endif
            > #endif

            > SKR 1.4 Turbo
            > ```
            > //#define X_DUAL_STEPPER_DRIVERS
            > #if ENABLED(X_DUAL_STEPPER_DRIVERS)
            >   #define INVERT_X2_VS_X_DIR    // Enable if X2 direction signal is opposite to X
            >   //#define X_DUAL_ENDSTOPS
            >   #if ENABLED(X_DUAL_ENDSTOPS)
            >     #define X2_USE_ENDSTOP _XMAX_
            >     #define X2_ENDSTOP_ADJUSTMENT  0
            >   #endif
            > #endif
            
            </details>

        *   <details>
            
            <summary> <i> Optional </i>- QUICK_HOME </summary>

            `Description in progress...`

            > Original
            > ```
            > //#define QUICK_HOME                          // If G28 contains XY do a diagonal move first

            > MKS Gen 1.4 | SKR 1.4 Turbo
            > ```
            > #define QUICK_HOME                          // If G28 contains XY do a diagonal move first
            
            </details>

        *   <details>
            
            <summary> <i> Erforderlich </i>- DISABLE_INACTIVE_Z </summary>

            `Description in progress...`

            > Original
            > ```
            > #define DISABLE_INACTIVE_Z true  // Set 'false' if the nozzle could fall onto your printed part!

            > SKR 1.4 Turbo | SKR 1.4 Turbo
            > ```
            > #define DISABLE_INACTIVE_Z false  // Set 'false' if the nozzle could fall onto your printed part!
            
            </details>

        *   <details>
            
            <summary> <i> Erforderlich </i>- HOST_ACTION_COMMANDS </summary>

            `Description in progress...`

            > Original
            > ```
            > //#define HOST_ACTION_COMMANDS

            > MKS Gen 1.4 | SKR 1.4 Turbo
            > ```
            > #define HOST_ACTION_COMMANDS
            
            </details>

        *   <details>
            
            <summary> <i> Erforderlich </i>- DIRECT_PIN_CONTROL </summary>

            `Description in progress...`

            > Original
            > ```
            > //#define DIRECT_PIN_CONTROL

            > MKS Gen 1.4 | SKR 1.4 Turbo
            > ```
            > #define DIRECT_PIN_CONTROL
            
            </details>

   *   <details>    

       <summary><b> root/Marlin/src/inc/Conditionals_LCD.h </b></summary>

        `Description in progress...`

        *   <details>
            
            <summary> <i> Erforderlich </i>- Z_HOME_TO_MIN </summary>

            `Description in progress...`

            > Original
            > ```
            >   #if Z_HOME_TO_MIN && TERN1(USES_Z_MIN_PROBE_PIN, ENABLED(USE_PROBE_FOR_Z_HOMING))

            > SKR 1.4 Turbo
            > ```
            >   #if Z_HOME_TO_MIN // && TERN1(USES_Z_MIN_PROBE_PIN, ENABLED(USE_PROBE_FOR_Z_HOMING))
            
            </details>       

</details>

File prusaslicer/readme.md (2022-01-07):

# PrusaSlicer
## **Software**
Beschrieben wird der Download, die Installation und die darauffolgende Konfiguration des PrusaSlicer's.

Zum Zeitpunkt dieser Dokumentation wird der PrusaSlicer und die Konfiguration in folgenden Versionen genutzt:

| Datei | Version | Link |
| :--- | ---: | :-: |
| PrusaSlicer | **2.3.3** | [GitHub UnusedSpace](./sources/) |
| Konfigurationssammlung | **\<NEUESTE>** | [GitHub UnusedSpace](./configs/) |
<br>

## Software - Download | Installation | Konfiguration

<details>
    <summary><b><i> Download </i></b></summary>

Der PrusaSlicer kann als Standalone (ohne Treiber/Firmware der PrusaPrinter) in aktueller Version über die offizielle [Webseite](https://www.prusa3d.com/page/prusaslicer_424/) herunter geladen werden. Die in dieser Dokumentation verwendete Version und geprüfte Konfigurationssammlungen sind unter oben angegebene Links erreichbar.

</details>

<details>
    <summary><b><i> Installation </i></b></summary>

Die Installation verläuft ohne besondere Konfigurationen. Sollte eine neuere Version des PrusaSlicer verfügbar sein, wird ein Download angeboten. Die Version 2.3.3 wurde erfolgreich auf Funktion geprüft. Die Benutzung anderer Releases erfolgen auf eigene Funktionsprüfung.
<br>

Trotz der *Standalone*-Definition können die vordefinierten Haken im Reiter ***Features*** unter ***Drivers*** und ***Utilities*** entfernt werden.

<center>

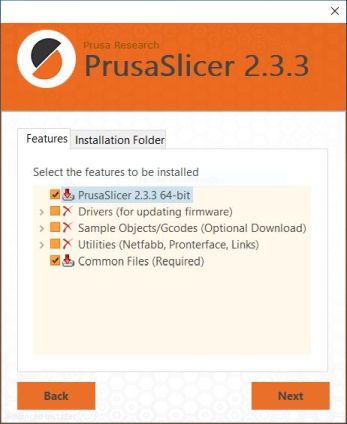
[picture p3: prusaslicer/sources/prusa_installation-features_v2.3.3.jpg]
Information: Prusa Installation-Features Nicht notwendige Features

</center>

</details>

<details>
    <summary><b><i> Konfiguration </i></b></summary>

Nach dem ersten Start von PrusaSlicer kann der Wizard abgebrochen und eine Konfiguration geladen werden:

> <c> *Import* </c>
> * `Datei > Import > Importiere Konfigurationssammlung...`

> <c> *Export* </c>
> * `Datei > Export > Konfigurationssammlung exportieren...`

</details>

<details>
    <summary><b><i> Druckbettkontur - Optional </i></b></summary>

Optional kann eine Druckbettkontur `*.stl` konfiguriert werden, welche im Ordner der Konfigurationssammlungen für den jeweiligen Drucker bereit liegt. Um eine fehlerfreie Funktion von PrusaSlicer sicher zu stellen, sollten die Darstellungsdateien unter dem PrusaSlicer eigenen Konfigurationspfad `%AppData%\PrusaSlicer` abgelegt werden.

<br>

<center>

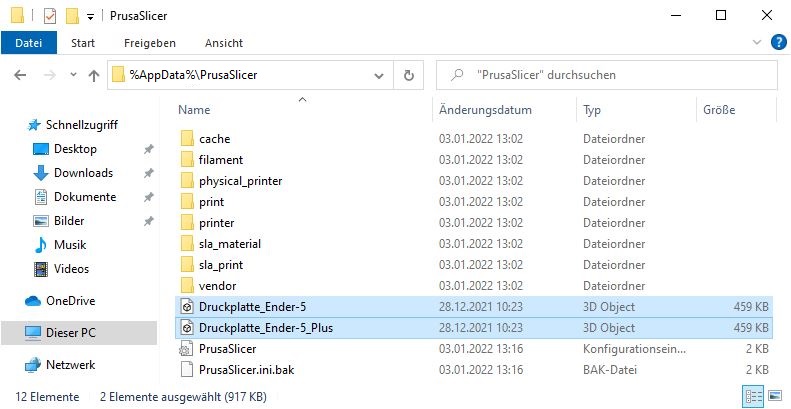
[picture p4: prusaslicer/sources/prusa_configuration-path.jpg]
PrusaSlicer Konfigurationspfad


</center>

<br>

> <u>Achtung</u>
>
> Konfigurierte Druckbettkonturen werden bei einem Export der Konfigurationssammlung lediglich verlinkt! Die Kontur `.stl` selbst wird <u>nicht</u> exportiert. Bei einem Import einer Konfigurationssammlung mit verlinkter Druckbettkontur müssen die `.stl` Dateien vorher in den Ordner `%AppData%\PrusaSlicer` abgelegt werden, anderweitig wird eine Fehlermeldung angezeigt.
>
> Sollte die `.stl` nicht wiederherstellbar sein, kann die Verknüpfung in der `xxxx-xx-xx PrusaSlicer_config_bundle.ini` in der Zeile `bed_custom_model = C:\\Users\\[...]\\Druckplatte_Ender-5.stl` aufgelöst werden, indem der Pfad hinter der Option entfernt wird.
> 
<br>

**Die Druckbettkontur für den jeweiligen Drucker zuweisen:**
1. Reiter `Druckereinstellungen`
2. Drucker auswählen, beispielsweise `Creality Ender-5 - Druckereinstellungen`
3. Einstellungssammlung `Allgemein`
4. Ansicht mindestens auf `Erweitert`
5. Im Feld `Größe und Koordinaten` bei `Druckbettkontur:` auf `Setzen ...`
6. Im Feld `Modell` auf `Laden...` und die passende Druckbettkontur laden
7. Jeweils mit `Öffnen` und `OK` bestätigen
<br><br>

<center>

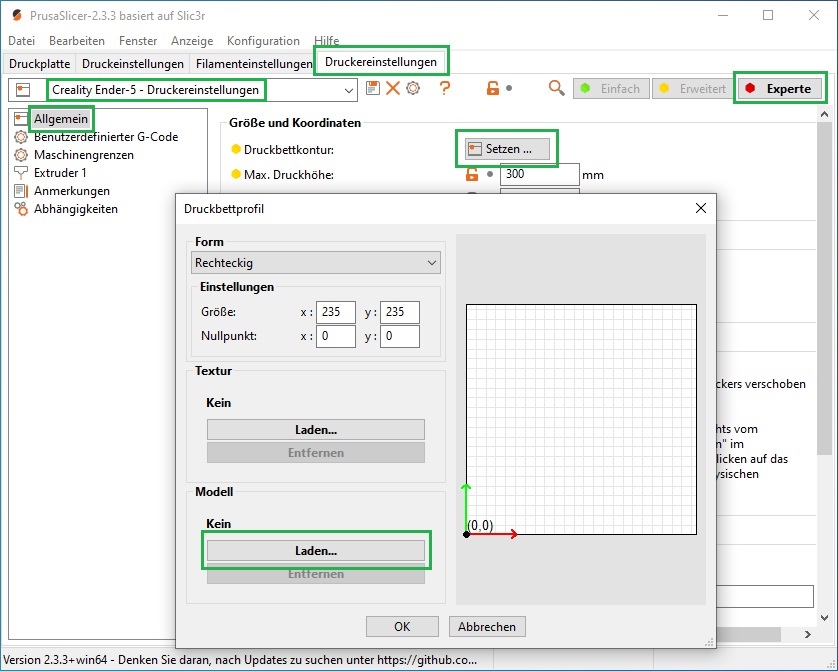
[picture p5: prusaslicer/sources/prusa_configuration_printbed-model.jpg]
Druckbettkontur einrichten


</center>

<center>

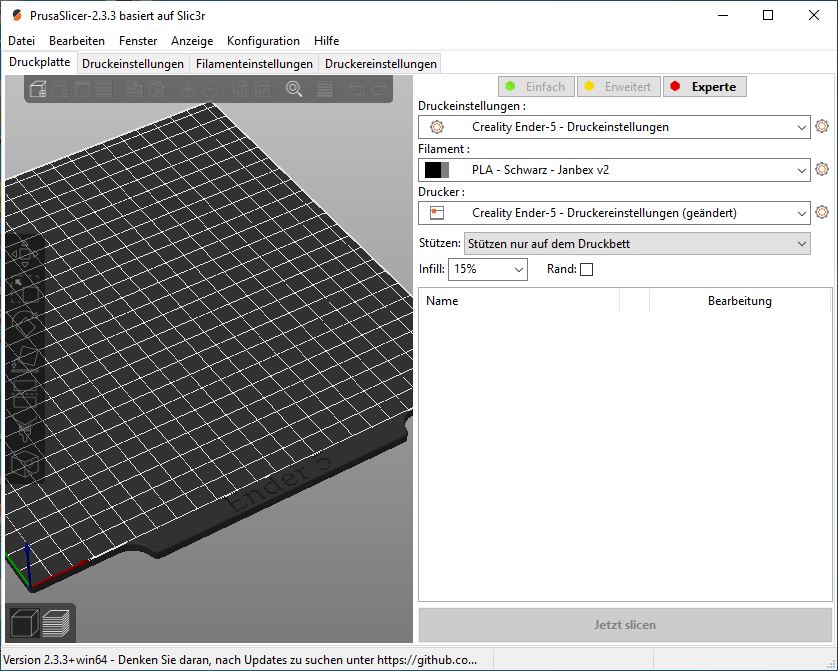
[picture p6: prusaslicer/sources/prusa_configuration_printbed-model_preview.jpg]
Druckbettkontur Beispielansicht


</center>

</details>

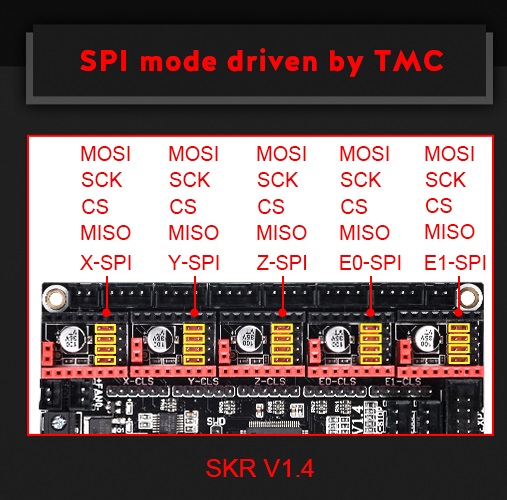
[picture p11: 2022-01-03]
marlinfw/datasheets/skr_1.4_turbo/skr_1.4_turbo_spi-diagram.jpg

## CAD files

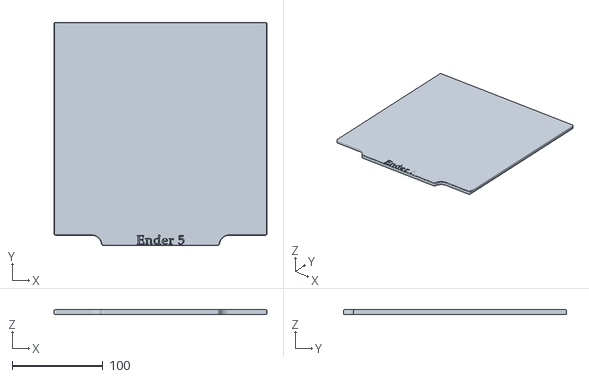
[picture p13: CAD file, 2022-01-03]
prusaslicer/configs/Druckplatte_Ender-5.stl
235.0 x 246.5 x 5.00

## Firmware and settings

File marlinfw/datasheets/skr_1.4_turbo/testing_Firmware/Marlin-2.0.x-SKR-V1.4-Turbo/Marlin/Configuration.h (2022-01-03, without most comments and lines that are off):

#pragma once
#define CONFIGURATION_H_VERSION 020006
#define STRING_CONFIG_H_AUTHOR "(none, default config)" // Who made the changes.
#define SHOW_BOOTSCREEN
#define SERIAL_PORT -1
#define SERIAL_PORT_2 0
#define BAUDRATE 115200
  #define MOTHERBOARD BOARD_BTT_SKR_V1_4_TURBO
#define EXTRUDERS 1
#define DEFAULT_NOMINAL_FILAMENT_DIA 1.75
#define TEMP_SENSOR_0 1
#define TEMP_SENSOR_1 0
#define TEMP_SENSOR_2 0
#define TEMP_SENSOR_3 0
#define TEMP_SENSOR_4 0
#define TEMP_SENSOR_5 0
#define TEMP_SENSOR_6 0
#define TEMP_SENSOR_7 0
#define TEMP_SENSOR_BED 1
#define TEMP_SENSOR_PROBE 0
#define TEMP_SENSOR_CHAMBER 0
#define DUMMY_THERMISTOR_998_VALUE 25
#define DUMMY_THERMISTOR_999_VALUE 100
#define MAX_REDUNDANT_TEMP_SENSOR_DIFF 10
#define TEMP_RESIDENCY_TIME     10  // (seconds) Time to wait for hotend to "settle" in M109
#define TEMP_WINDOW              1  // (°C) Temperature proximity for the "temperature reached" timer
#define TEMP_HYSTERESIS          3  // (°C) Temperature proximity considered "close enough" to the target
#define TEMP_BED_RESIDENCY_TIME 10  // (seconds) Time to wait for bed to "settle" in M190
#define TEMP_BED_WINDOW          1  // (°C) Temperature proximity for the "temperature reached" timer
#define TEMP_BED_HYSTERESIS      3  // (°C) Temperature proximity considered "close enough" to the target
#define HEATER_0_MINTEMP   5
#define HEATER_1_MINTEMP   5
#define HEATER_2_MINTEMP   5
#define HEATER_3_MINTEMP   5
#define HEATER_4_MINTEMP   5
#define HEATER_5_MINTEMP   5
#define HEATER_6_MINTEMP   5
#define HEATER_7_MINTEMP   5
#define BED_MINTEMP        5
#define HEATER_0_MAXTEMP 275
#define HEATER_1_MAXTEMP 275
#define HEATER_2_MAXTEMP 275
#define HEATER_3_MAXTEMP 275
#define HEATER_4_MAXTEMP 275
#define HEATER_5_MAXTEMP 275
#define HEATER_6_MAXTEMP 275
#define HEATER_7_MAXTEMP 275
#define BED_MAXTEMP      150
#define PIDTEMP
#define BANG_MAX 255     // Limits current to nozzle while in bang-bang mode; 255=full current
#define PID_MAX BANG_MAX // Limits current to nozzle while PID is active (see PID_FUNCTIONAL_RANGE below); 255=full current
#define PID_K1 0.95      // Smoothing factor within any PID loop
  #define DEFAULT_Kp 22.2
  #define DEFAULT_Ki 1.08
  #define DEFAULT_Kd 114
#define MAX_BED_POWER 255 // limits duty cycle to bed; 255=full current
  #define PID_FUNCTIONAL_RANGE 10 // If the temperature difference between the target temperature and the actual temperature
#define PREVENT_COLD_EXTRUSION
#define EXTRUDE_MINTEMP 170
#define PREVENT_LENGTHY_EXTRUDE
#define EXTRUDE_MAXLENGTH 200
#define THERMAL_PROTECTION_HOTENDS // Enable thermal protection for all extruders
#define THERMAL_PROTECTION_BED     // Enable thermal protection for the heated bed
#define THERMAL_PROTECTION_CHAMBER // Enable thermal protection for the heated chamber
#define USE_XMIN_PLUG
#define USE_YMIN_PLUG
#define USE_ZMIN_PLUG
#define ENDSTOPPULLUPS
#define X_MIN_ENDSTOP_INVERTING false // Set to true to invert the logic of the endstop.
#define Y_MIN_ENDSTOP_INVERTING false // Set to true to invert the logic of the endstop.
#define Z_MIN_ENDSTOP_INVERTING false // Set to true to invert the logic of the endstop.
#define X_MAX_ENDSTOP_INVERTING false // Set to true to invert the logic of the endstop.
#define Y_MAX_ENDSTOP_INVERTING false // Set to true to invert the logic of the endstop.
#define Z_MAX_ENDSTOP_INVERTING false // Set to true to invert the logic of the endstop.
#define Z_MIN_PROBE_ENDSTOP_INVERTING false // Set to true to invert the logic of the probe.
#define DEFAULT_AXIS_STEPS_PER_UNIT   { 80, 80, 400, 93 }
#define DEFAULT_MAX_FEEDRATE          { 500, 500, 5, 25 }
#define DEFAULT_MAX_ACCELERATION      { 500, 500, 100, 5000 }
#define DEFAULT_ACCELERATION          500    // X, Y, Z and E acceleration for printing moves
#define DEFAULT_RETRACT_ACCELERATION  500    // E acceleration for retracts
#define DEFAULT_TRAVEL_ACCELERATION   500    // X, Y, Z acceleration for travel (non printing) moves
#define DEFAULT_EJERK    5.0  // May be used by Linear Advance
  #define JUNCTION_DEVIATION_MM 0.013 // (mm) Distance from real junction edge
  #define JD_HANDLE_SMALL_SEGMENTS    // Use curvature estimation instead of just the junction angle
#define Z_MIN_PROBE_USES_Z_MIN_ENDSTOP_PIN
#define NOZZLE_TO_PROBE_OFFSET { 10, 10, 0 }
#define PROBING_MARGIN 10
#define XY_PROBE_SPEED (133*60)
#define Z_PROBE_SPEED_FAST HOMING_FEEDRATE_Z
#define Z_PROBE_SPEED_SLOW (Z_PROBE_SPEED_FAST / 2)
#define Z_CLEARANCE_DEPLOY_PROBE   10 // Z Clearance for Deploy/Stow
#define Z_CLEARANCE_BETWEEN_PROBES  5 // Z Clearance between probe points
#define Z_CLEARANCE_MULTI_PROBE     5 // Z Clearance between multiple probes
#define Z_PROBE_LOW_POINT          -2 // Farthest distance below the trigger-point to go before stopping
#define Z_PROBE_OFFSET_RANGE_MIN -20
#define Z_PROBE_OFFSET_RANGE_MAX 20
#define X_ENABLE_ON 0
#define Y_ENABLE_ON 0
#define Z_ENABLE_ON 0
#define E_ENABLE_ON 0 // For all extruders
#define DISABLE_X false
#define DISABLE_Y false
#define DISABLE_Z false
#define DISABLE_E false             // Disable the extruder when not stepping
#define DISABLE_INACTIVE_EXTRUDER   // Keep only the active extruder enabled
#define INVERT_X_DIR false
#define INVERT_Y_DIR false
#define INVERT_Z_DIR true
#define INVERT_E0_DIR false
#define INVERT_E1_DIR false
#define INVERT_E2_DIR false
#define INVERT_E3_DIR false
#define INVERT_E4_DIR false
#define INVERT_E5_DIR false
#define INVERT_E6_DIR false
#define INVERT_E7_DIR false
#define X_HOME_DIR -1
#define Y_HOME_DIR -1
#define Z_HOME_DIR -1
#define X_BED_SIZE 200
#define Y_BED_SIZE 200
#define X_MIN_POS 0
#define Y_MIN_POS 0
#define Z_MIN_POS 0
#define X_MAX_POS X_BED_SIZE
#define Y_MAX_POS Y_BED_SIZE
#define Z_MAX_POS 200
#define MIN_SOFTWARE_ENDSTOPS
  #define MIN_SOFTWARE_ENDSTOP_X
  #define MIN_SOFTWARE_ENDSTOP_Y
  #define MIN_SOFTWARE_ENDSTOP_Z
#define MAX_SOFTWARE_ENDSTOPS
  #define MAX_SOFTWARE_ENDSTOP_X
  #define MAX_SOFTWARE_ENDSTOP_Y
  #define MAX_SOFTWARE_ENDSTOP_Z
#define HOMING_FEEDRATE_XY (50*60)
#define HOMING_FEEDRATE_Z  (4*60)
#define VALIDATE_HOMING_ENDSTOPS
#define EEPROM_SETTINGS     // Persistent storage with M500 and M501
#define EEPROM_CHITCHAT       // Give feedback on EEPROM commands. Disable to save PROGMEM.
#define EEPROM_BOOT_SILENT    // Keep M503 quiet and only give errors during first load
  #define EEPROM_AUTO_INIT  // Init EEPROM automatically on any errors.
#define HOST_KEEPALIVE_FEATURE        // Disable this if your host doesn't like keepalive messages
#define DEFAULT_KEEPALIVE_INTERVAL 2  // Number of seconds between "busy" messages. Set with M113.
#define BUSY_WHILE_HEATING            // Some hosts require "busy" messages even during heating
#define PREHEAT_1_LABEL       "PLA"
#define PREHEAT_1_TEMP_HOTEND 185
#define PREHEAT_1_TEMP_BED     45
#define PREHEAT_1_FAN_SPEED     255 // Value from 0 to 255
#define PREHEAT_2_LABEL       "ABS"
#define PREHEAT_2_TEMP_HOTEND 240
#define PREHEAT_2_TEMP_BED    0
#define PREHEAT_2_FAN_SPEED     255 // Value from 0 to 255
#define PRINTJOB_TIMER_AUTOSTART
#define LCD_LANGUAGE en
#define DISPLAY_CHARSET_HD44780 JAPANESE
#define LCD_INFO_SCREEN_STYLE 0
#define SDSUPPORT
#define INDIVIDUAL_AXIS_HOMING_MENU
#define SPEAKER
#define REPRAP_DISCOUNT_FULL_GRAPHIC_SMART_CONTROLLER
#define SOFT_PWM_SCALE 0
#define SERVO_DELAY { 300 }

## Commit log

2022-01-03 Dokumentation erstellt
    [Configuration.h, Configuration_adv.h, Druckplatte_Ender-5.stl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]
2022-01-05 Aktualisiert
    - Umgestaltung der Dokumentation
    - Erweiterung der Dokumentation
    [Configuration.h, Configuration_adv.h, Druckplatte_Ender-5.stl]
2022-01-05 aktualisiert
    Dokumentation marlinfw
    - BLTOUCH_SET_5V_MODE entfernt
2022-01-07 Aktualisiert
    - Dokumentation MarlinFw aktualisiert
2022-01-13 Create 2022-01-13 PrusaSlicer_config_bundle.ini
    Filament
    - PLA - Schwarz - Janbex v2 > Extrusionsfaktor eingestellt
    Drucker
    + Ender-5 Plus - Glas hinzugefügt (wg. Bettgröße)
    + Ender-5 Plus - GFK hinzugefügt (wg. Bettgröße)
2022-01-13 Update 2022-01-13 PrusaSlicer_config_bundle.ini
    + Benutzerdefinierter G-Code > Start
    > NozzleTemp zum Autoleveln anpassen
    > BedTemp zum Homen und Autoleveln anpassen und warten
    > Erneut Homen
    > Autoleveln
    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
2022-01-13 Create 2022-01-13 PrusaSlicer_config_bundle.ini
    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
2022-01-23 Aktualisiert
    PrusaSlicer
    - readme.md angepasst
    Raspberry
    - readme.md erstellt
    MarlinFw
    -readme.md angepasst
    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
2022-02-23 Update readme.md
    Grundbeschreibung OctoPrint mehrere Instanzen auf einem Raspberry

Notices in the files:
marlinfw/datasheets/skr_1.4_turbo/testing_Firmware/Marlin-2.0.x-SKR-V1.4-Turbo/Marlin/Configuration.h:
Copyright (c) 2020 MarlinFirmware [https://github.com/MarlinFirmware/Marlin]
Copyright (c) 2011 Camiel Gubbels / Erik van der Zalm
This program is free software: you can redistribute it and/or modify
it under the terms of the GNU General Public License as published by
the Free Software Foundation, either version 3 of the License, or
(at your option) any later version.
